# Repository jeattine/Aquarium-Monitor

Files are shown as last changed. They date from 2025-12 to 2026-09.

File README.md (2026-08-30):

# Aquarium monitor

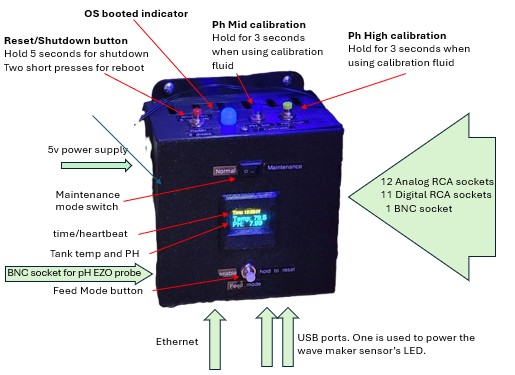
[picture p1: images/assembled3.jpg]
Assembled3


Python-based aquarium monitor program running under the Raspberry Pi OS Lite Linux operating system on a Raspberry Pi 4 board. A Adafruit Perma-Proto Hat is mounted on the board to house two MCP3008 10-bit ADC with SPI interface. An Atlas scientific PH EZO with isolated carrier board is attach to the I2C interface of the processor. The MCP3008's and the PH EZO provide the analog inputs to the monitor. The HAT also provides solder pads for each of the other GPIO pins used as digital inputs. The monitor has 23 RCA sockets and one BNC socket for input of the sensors. The BNC socket is used for the PH probe. One RCA socket is used for output for the alarm/maintenance_mode LED indicator. The monitor has a button to force a reset or a shutdown of the OS/monitor and a switch to enter a maintenance mode which disables alerts and enables pH calibration. There is also a Feed Mode button that allows pumps to be turned off during feeding without generating alerts. The monitor provides two buttons for the calibration of the PH probe, with a PH-Mid and a PH-High that can be set to the values of the calibration fluid in the configuration file or the override file. The calibration is saved internally and does not rely on providing external calibration data. When performing the calibration, the display will show *Maintenance* text along with the current pH value. The pH value display is helpful during pH calibration so that it can be seen that the PH values have stabilized with the probe in the calibration fluid. The condition of the pH probe in terms of a percentage from an ideal probe will be displayed in the OLED screen for 4 seconds after calibrating. A log file containing hourly snapshots of the PH value, Temperature, Calibration actions, Feed mode on/off, maintenance mode on/off, and Alerts can be observed in a cloud folder. A status file containing current information from all the sensors can be observed in the same cloud folder (dropbox and onedrive supported). I am using Dropbox as my cloud provider due to the simplicity of setting this up on Linux. The storing of the status and log file is accomplished using 'rclone copyto'. Monitor alerts are surfaced by emails sent to the recipients listed in the configuration file. The monitor will autostart after the Linux OS boots. It is started via a service and set to be restarted if it abnormally terminates or hangs using the WATCHDOG support in Linux. 

The program design has a 'Main' that constructs a Control object and loops calling methods on the Control object instantiation. 'Main' will stay in a continuous loop until an exception or a termination event causes it to exit. The input to the program is a config.txt file expected to be in the current directory. This file is composed of two sections. The first section assigns the port numbers of the hardware to various classes to read and process the sensor data connected to those port inputs. Some examples are classes to monitor temperature, Flow, water level, and light. These classes are derived from either a GPIO_Digital or a GPIO_Analog class, depending on the type of sensor. The GPIO_Digital class, GPIO_Analog class, and PH class are each derived from the Sensor base class. In addition to the port assignment to classes, this section of the config file also gives a descriptive name to each port input and defines the expected values/ranges/time-periods for operation. Another input to the program is the override.txt file. This file resides at a cloud location, either Dropbox or Onedrive depending on how the system is configured. This override file provides a convenient way to modify a subset of the settings in the config.txt file. For example when going on vacation I may want to modify the recipient list of the email alerts. I can do this by simply modifying the override file in the cloud folder from any device that has access to that folder. 

The utility Tailscale is installed on the monitor and on personal devices. This provides direct ssh access to the monitor via a split VPN tunnel directly between the personal devices and the monitor, allowing safe client SSH access to the monitor from outside the local home network. SSH access is useful if I need to perform a more drastic administrative or service action when away from home. When away from my primary laptop, the need may arise to modify the config.txt or the aquamon.py file. My iPAD and phone both have a dropbox application and Tailscale. On the iPAD I am using the Terminal# app which will get me into an SSH session. On the phone I use Termux. On the monitor I have two aliases set up: update-aquamon and update_config. They will use 'rclone copyto' to copy files from my local GitHub repository located in dropbox to the monitor. From there a systemctl restart put the new files in play. For an editor on the iPAD I am using Runestone. It's simple, lightweight, and color-codes nicely editing python code.

Code structure:

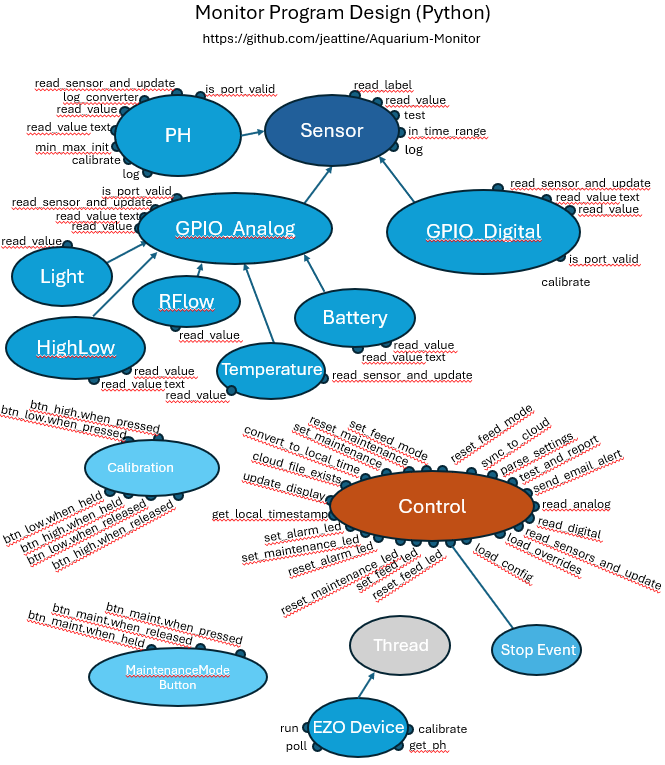
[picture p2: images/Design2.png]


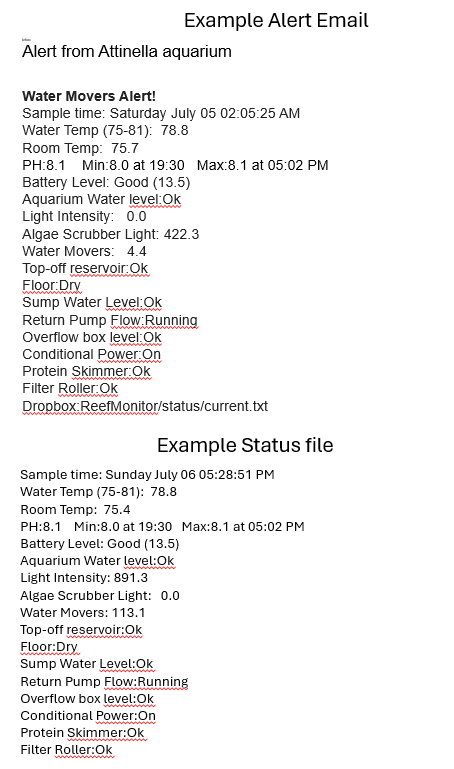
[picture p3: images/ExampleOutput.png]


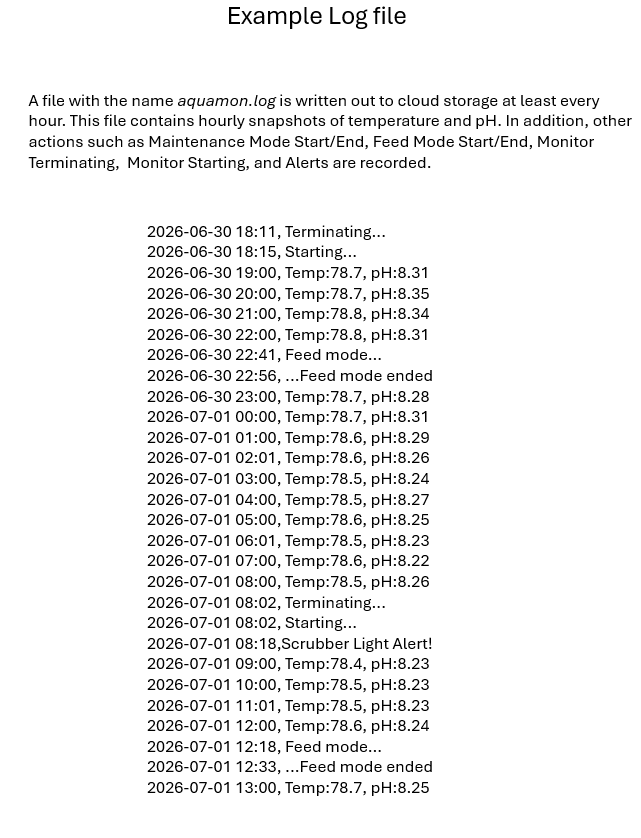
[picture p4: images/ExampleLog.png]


This is the bigger picture, showing the network interfaces and wiring to the various sensors:
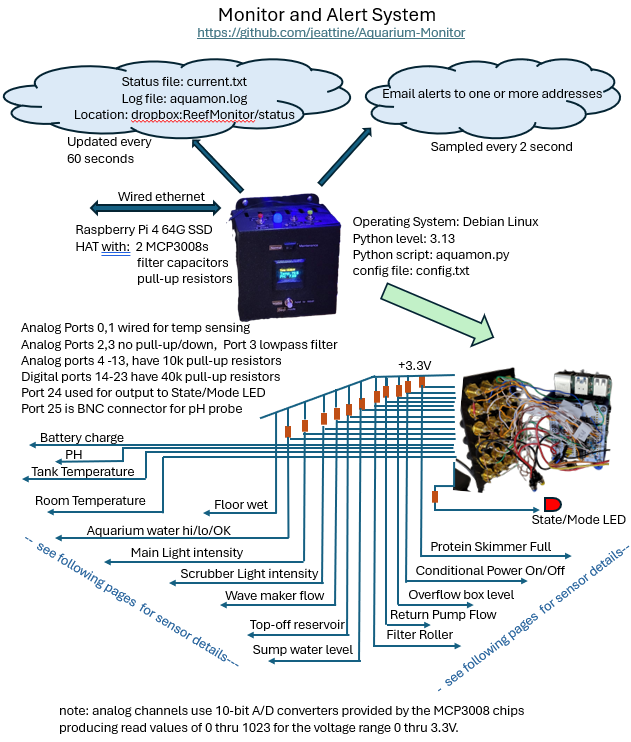
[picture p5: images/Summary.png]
Summary


The Raspberry Pi board, Perma-Proto Hat with the two MCP3008 ICs, and the wiring to the RCA inputs:

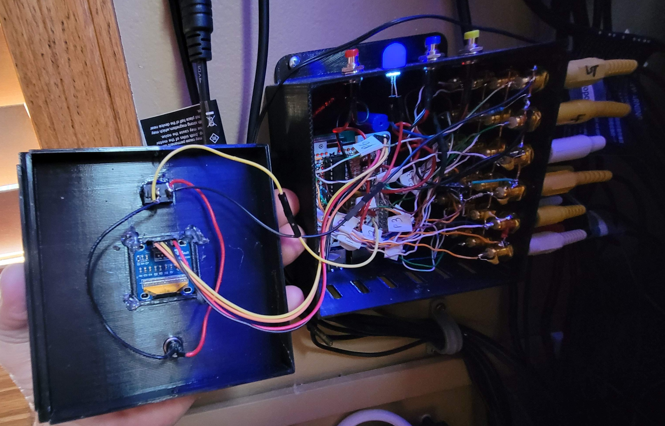
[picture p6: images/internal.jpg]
Internals


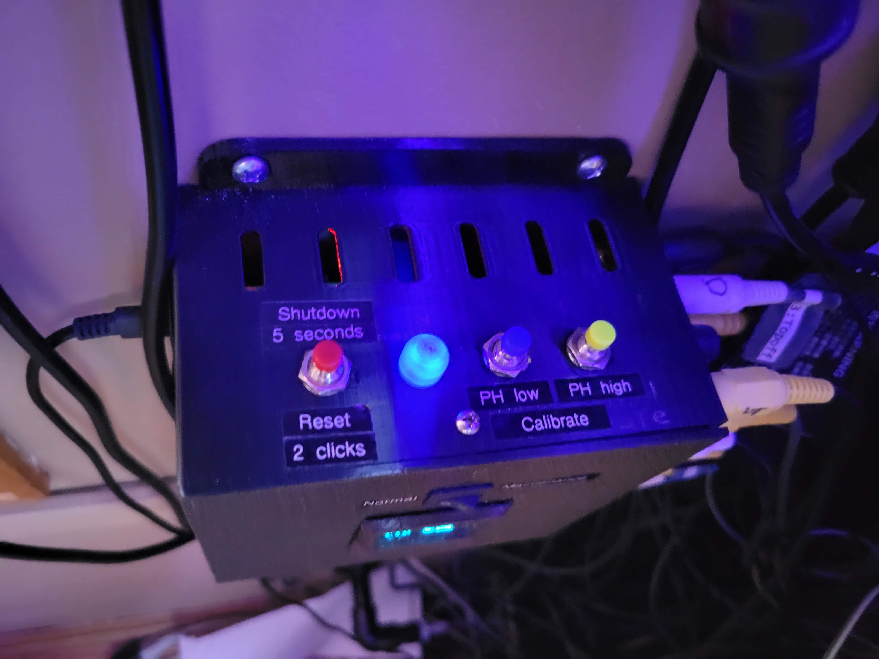
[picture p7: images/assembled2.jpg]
Assembled2


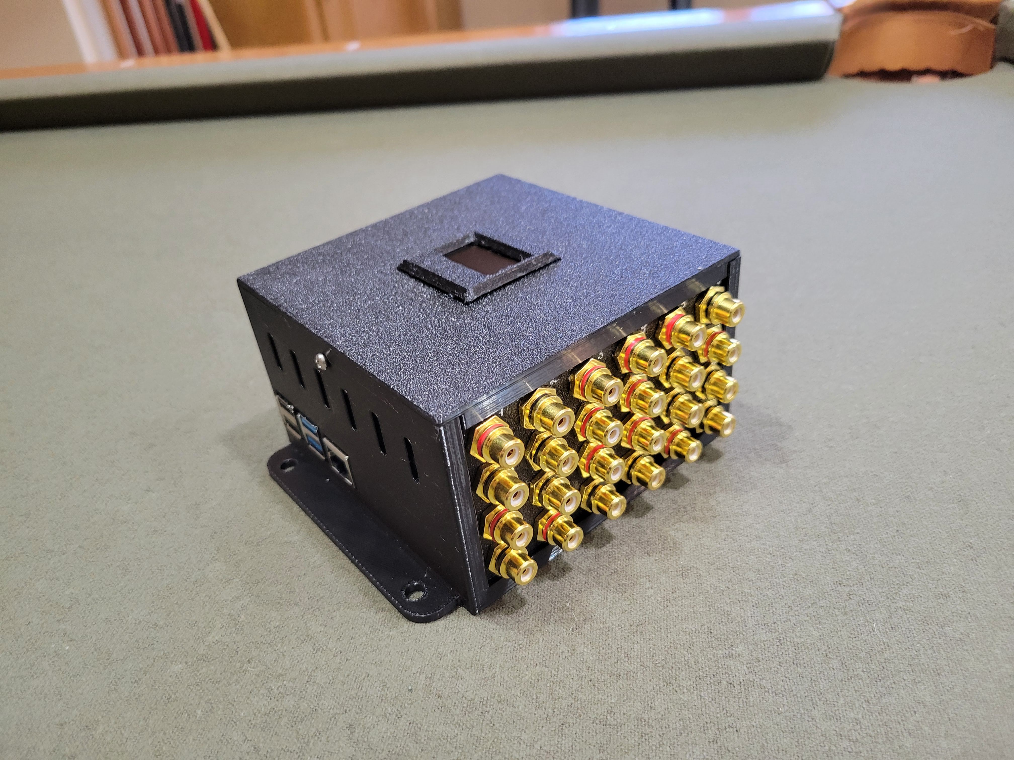
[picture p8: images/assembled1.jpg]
Assembled1


Internal wiring schematic:

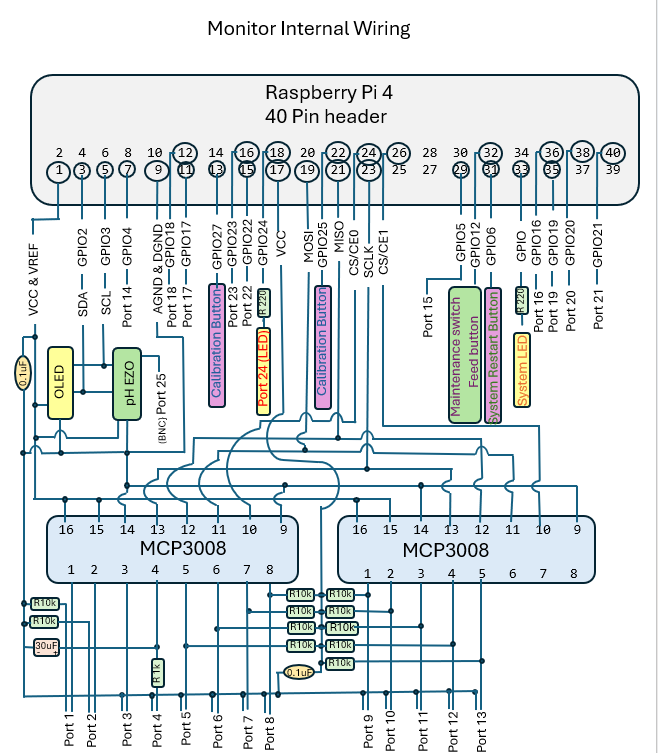
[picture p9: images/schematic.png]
Schematic


The following images show the various sensors that feed the monitor through the RCA ports:
  
***
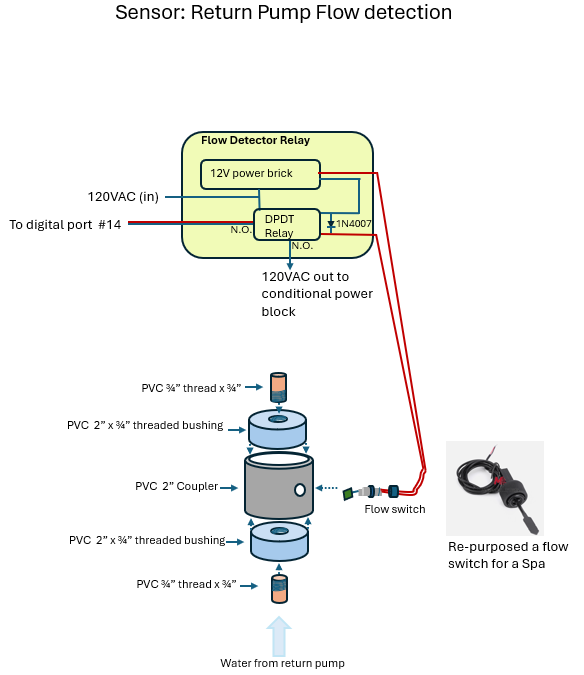
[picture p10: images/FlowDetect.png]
Flow Detection

  
***
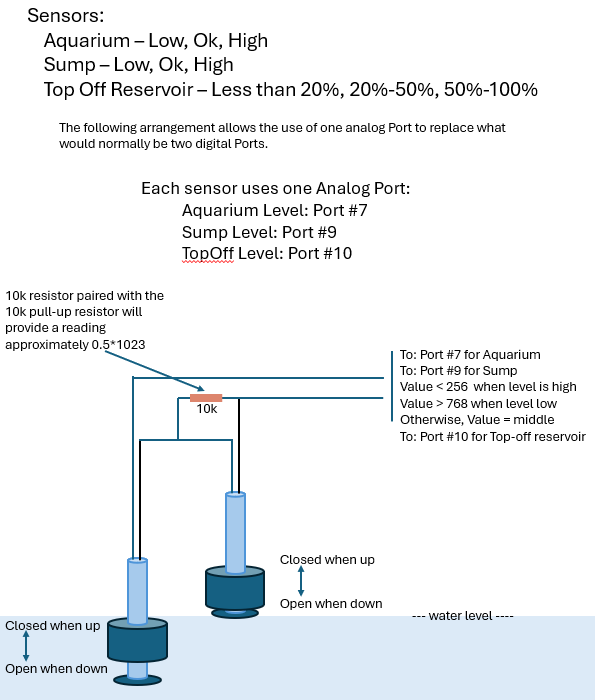
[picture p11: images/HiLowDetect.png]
Hi Low Level Detection

  
***
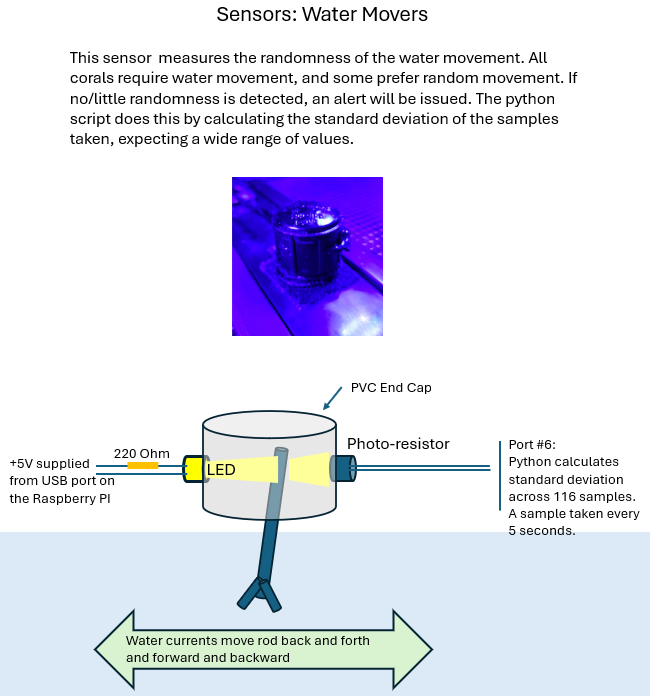
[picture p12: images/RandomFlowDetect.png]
Random Flow Detect

  
***
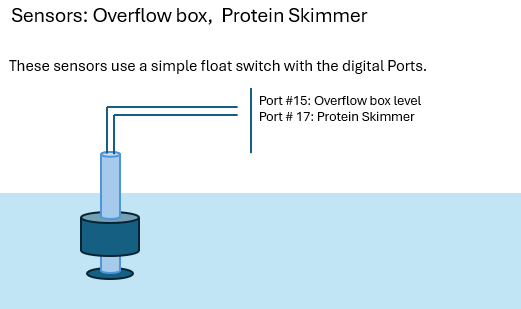
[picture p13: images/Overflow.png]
Overflow Detect

  
***
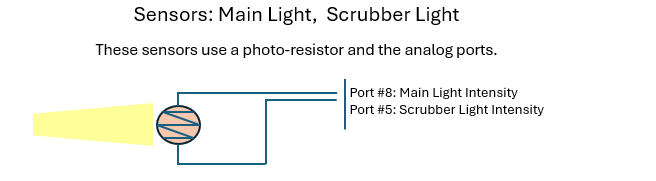
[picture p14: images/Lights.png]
Light Detect

  
***
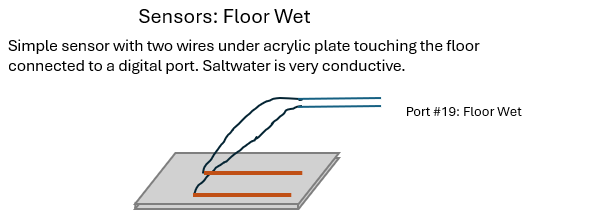
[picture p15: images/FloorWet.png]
Floor Wet Detect

  
***
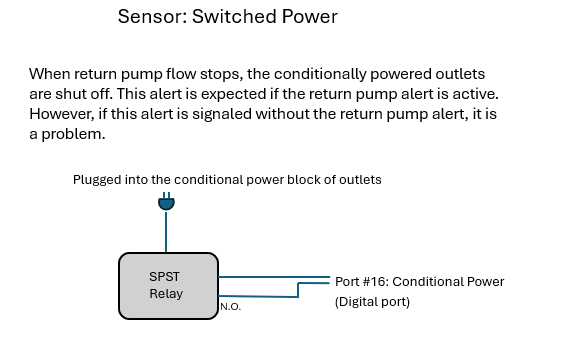
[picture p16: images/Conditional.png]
Conditional Detect

  
***
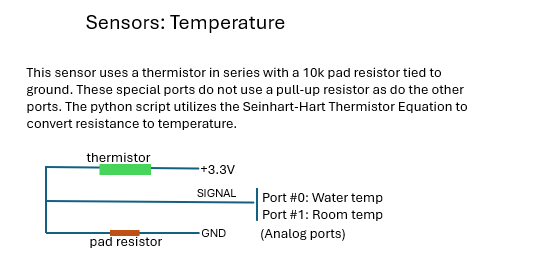
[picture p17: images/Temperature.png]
Temperature Detect

  
***
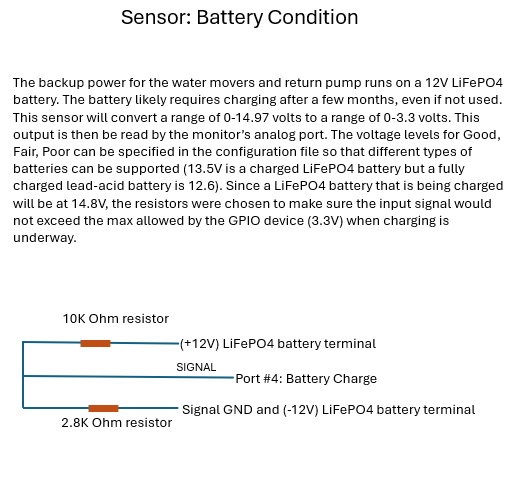
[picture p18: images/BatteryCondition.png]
Battery Condition

  
***
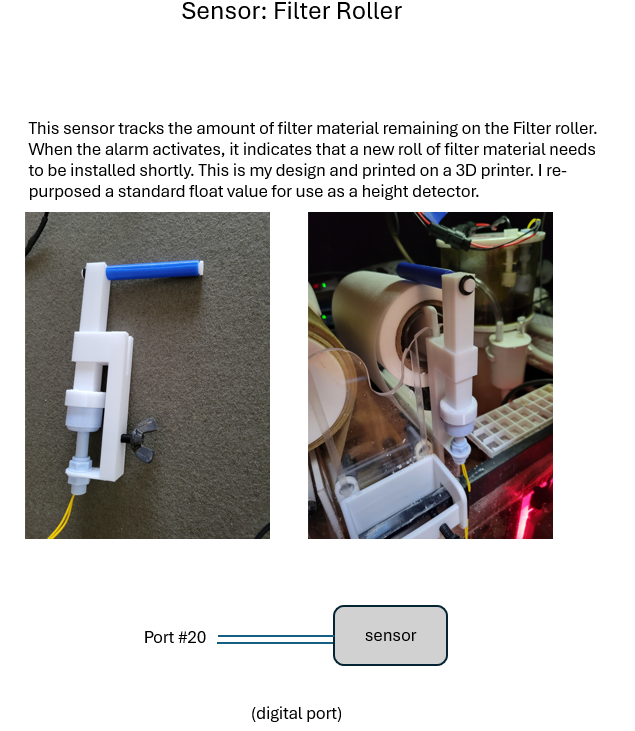
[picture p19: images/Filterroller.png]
Filter Roller

  
***
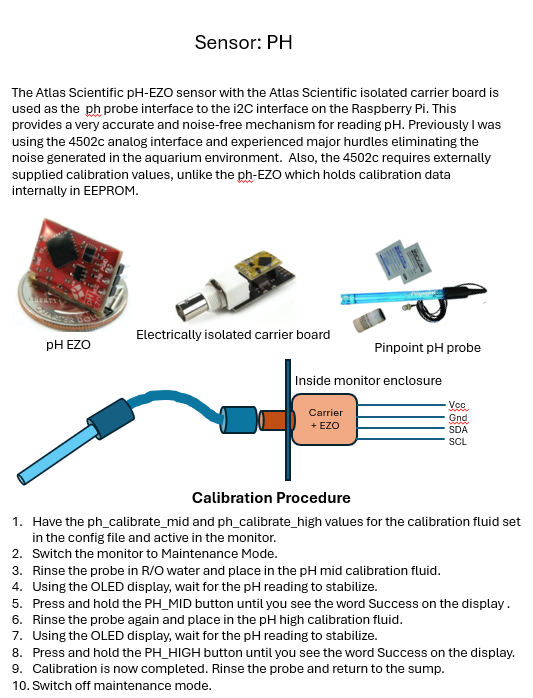
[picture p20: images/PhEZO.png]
PH

***

## Raspberry Pi Setup for the Aquarium Monitor

### Flash the OS

1.  Download the **Raspberry Pi Imager** on your Windows 11 machine.
2.  Select **OS**: _Raspberry Pi OS (64-bit) Lite_ (You don't need a desktop GUI).
3.  Select **Storage**: Your microSD card.
4.  **Gear Icon (Edit Settings)**:
    *   **Set hostname:** e.g., aquamon-local
    *   **Set username/password:** (e.g., pi and your chosen password).
    *   **Configure Wireless LAN:** Enter your SSID and Password.
    *   **Services Tab:** Check **Enable SSH** and use password authentication.
5.  Click **Write**.

### Connect via SSH

Once the card is flashed, pop it into the Pi and power it up. Wait about 2 minutes for the first boot.

1.  Open **PowerShell** on Windows 11.
2.  Type:
    ```
	ssh pi@aquamon.local
	```
	(replace pi and aquamon with the credentials you set).
3.  If it asks about "authenticity of host," type:
    ```
	yes
	```
4.  Enter your password. You are now "inside" the Pi.
5.  Finish and Reboot:
    ```
	sudo reboot
    ```	
	(You'll be disconnected; wait a minute and SSH back in).

### Environment Setup and Libraries

Modern Raspberry Pi OS (Bookworm) requires a **Virtual Environment (venv)** to prevent breaking system-wide packages.

### Update the system

```
sudo apt update sudo apt upgrade -y  
sudo apt install i2c-tools rclone swig liblgpio-dev python3-dev build-essential -y  
sudo apt-get install fonts-freefont-ttf  
curl -fsSL https://tailscale.com/install.sh | sh  
sudo tailscale up  
```

### Create a project folder

```
mkdir reef_monitor && cd reef_monitor
```

### Create and activate a Virtual Environment

```shell
python -m venv env
source env/bin/activate
```

### Install the necessary python libraries

```shell
pip install gpiozero spidev luma.oled smbus2 rpi-lgpio sdnotify  
```

### Enable Hardware Interfaces

The design uses **SPI** for the MCP3008s and **I2C** for the OLED and pH EZO. These are disabled by default.  
1.  In the SSH terminal:
    ```shell
	sudo raspi-config
	```
1.  Navigate to **Interface Options**.
1.  Enable **I2C** and **SPI**.

### Transfer the code

Since we are on Windows, the easiest way to move the .py and config.txt files to the Pi is using **SCP** (Secure Copy). Open a _new_ PowerShell window on your Windows desktop (not the one logged into the Pi) and run:  

```shell
scp aquarium_script.py config.txt pi@aquamon.local:~/reef_monitor/
```

### Set the environment variables and activate environment

The code uses os.environ.get('AQUAMON\_EMAIL'), etc. We need to define these on the Pi so the script can see them.  
1.  In your SSH session, open the profile file:
    ````shell
    nano ~/.bashrc
	````
2.  Scroll to the bottom and add the following:
    ````text
    export AQUAMON_EMAIL=[your_email@gmail.com](mailto:your_email@gmail.com)  
    export AQUAMON_EMAIL_PW="your_app_password"
	````
3.  Source the script:
    ````text
    source ~/reef_monitor/env/bin/activate
	````
4.  Save (**Ctrl+O, Enter**) and Exit (**Ctrl+X**).
5.  Refresh the variables:
    ```shell 
    source ~/.bashrc
	```

### Run and Automate

To test it: 

```shell 
python reef_monitor/aquarium_script.py
```
### Setup a systemd service to have it start on boot

In the SSH session, run the following command to create a new service file:

```shell
sudo nano /etc/systemd/system/reef_monitor.service
```
Service file:  
```text
[Unit]  
Description=Reef Aquarium Monitor Script  
After=network-online.target  
Wants=network-online.target  

[Service]
Type=notify  
User=aquamon  
# Add Environment variable here  
Environment="AQUAMON_EMAIL=aquamonemail@gmail.com"  
Environment="AQUAMON_EMAIL_PW=abcdefghijklmnop"  
# Path to your python interpreter and your script  
ExecStart=/home/aquamon/reef_monitor/env/bin/python3 -u /home/aquamon/reef_monitor/aquamon.py  
# Working directory (helps if your script loads fonts or images from its own folder)  
WorkingDirectory=/home/aquamon/reef_monitor  
# Restart logic  
Restart=always  
# Wait 10 seconds before restarting to prevent rapid-fire loops  
RestartSec=10s
WatchdogSec=180  

[Install]  
WantedBy=multi-user.target  
```

During developement/debug I would typically stop the service and run the the monitor in an ssh'ed terminal session. 

You must then enable the service. This creates a symlink (a shortcut) that tells the system to run this script when it reaches multi-user.target (normal bootup).  
```shell
sudo systemctl enable reef_monitor.service  
```
I also have a reef shutdown service that runs separately to provide restart and shutdown via buttons. This would done as a separate service so that if the monitor ends or is hung, the restart and shutdown button actions would still be active.

```shell
sudo nano /etc/systemd/system/reef_shutdown.service  
```

```text
[Unit]  
Description=Reef Monitor Hardware Shutdown Button  
After=network.target

[Service]  
Type=simple  
ExecStart=/usr/bin/python3 /home/aquamon/reef_monitor/shutdown_button.py  
Restart=always  
RestartSec=5  
User=root

[Install]  
WantedBy=multi-user.target  
```

Also enable this service:
```shell
sudo systemctl enable shutdown.service  
```

### Install Rclone

The command rclone copy is **one-way only**. It behaves like an "upload" or a "download". It will **not** try to synchronize with all files in the cloud folder.

*   Run rclone config on Raspberry Pi.
*   Name it dropbox, pick the dropbox number.
*   When it asks **"Use auto config?"**, type **n** (No).
*   Copy the command given (e.g., rclone authorize "dropbox") and run it on your Windows PC.
*   Log in to Dropbox in your browser, click **Allow**, and paste the resulting token back into the Pi.

### Setup aliases

```shell
nano ~/.bash_aliases  
```

```text
alias update-aquamon='rclone copyto dropbox:GitHub/Aquarium-Monitor/aquamon.py ~/reef_monitor/aquamon.py && echo "aquamon.py updated from local repo"'
alias update-config='rclone copyto dropbox:GitHub/Aquarium-Monitor/config.txt ~/reef_monitor/config.txt && echo "config.txt updated from local repo"'
alias monitor-logs='TZ="America/Chicago" journalctl -u reef_monitor.service --no-pager -n 40'
```

The update-\* aliases make code testing convenient. SSH to the system from your device, and assuming your device has dropbox access to the local repository directory, run the scripts to update the code and configuration files as needed.

## Managing the Monitor  

When the monitor is up and running via the reef_monitor service, use these commands to work with it:

| Task | Command |
| --- | --- |
| Check if it's running | sudo systemctl status reef\_monitor.service |
| Stop the monitor | sudo systemctl stop reef\_monitor.service |
| Restart monitor | sudo systemctl restart reef\_monitor.service |
| View past logs | monitor-logs |
| View live logs | sudo journalctl -u reef_monitor.service -f |
| Update monitor code | update-aquamon |
| Update config file | update-config |

## Tailscale periodic re-authentication

Tailscale requires periodic re-authentication (by default every 180 days) for security. Because Tailscale does not have its own separate username/password system, you authenticated using an existing Identity Provider (SSO) such as Google, Microsoft, GitHub, or Apple.  

**Step 1:** Identify Your Account.  Try these quick methods to figure out which email/account you used:Check your email inboxes: Search your personal email accounts (Google/Gmail, Microsoft, etc.) for Tailscale or "Welcome to Tailscale". Check browser history: Go to login.tailscale.com in your web browser. If you have active sessions or stored cookies, it may auto-redirect to your admin console or highlight the account provider you previously selected.

**Step 2:** Re-authenticate Your LaptopOpen the Tailscale desktop app or run tailscale up in your terminal.When prompted, log in using the identity provider (e.g., Google) linked to your primary account.  

**Step 3:** Re-authenticate Your Raspberry PiOnce you are logged into your primary account on your browser: Local Terminal Access: If your Pi is nearby, log in via a local terminal (or local network SSH) and run:

```shell 
sudo tailscale up --force-reauth
```

Follow the URL: Copy the URL output by the command and paste it into the browser where you are logged into Tailscale.

**(Optional) Disable Key Expiry:** To prevent the Pi from disconnecting again in 180 days: Go to the Tailscale Admin Console.Find your Raspberry Pi in the Machines list.Click the ... menu next to it and select Disable key expiry. You can do this for other mobile devices such as ipads and android phones.

## Monitor Enclosure

The enclosure and related parts were all printed on a 3D printer. I have included the FreeCad source files for these parts. They can be modified with FreeCad and/or exported to 3mf files for printing.  

***

# The Big Picture

The following diagrams depict my overall aquarium environment. The first diagram shows the interconnections of pumps, filters, lights, scrubber, monitor, etc.. The second diagram shows the management and plumbing of both saltwater and R/O water.  

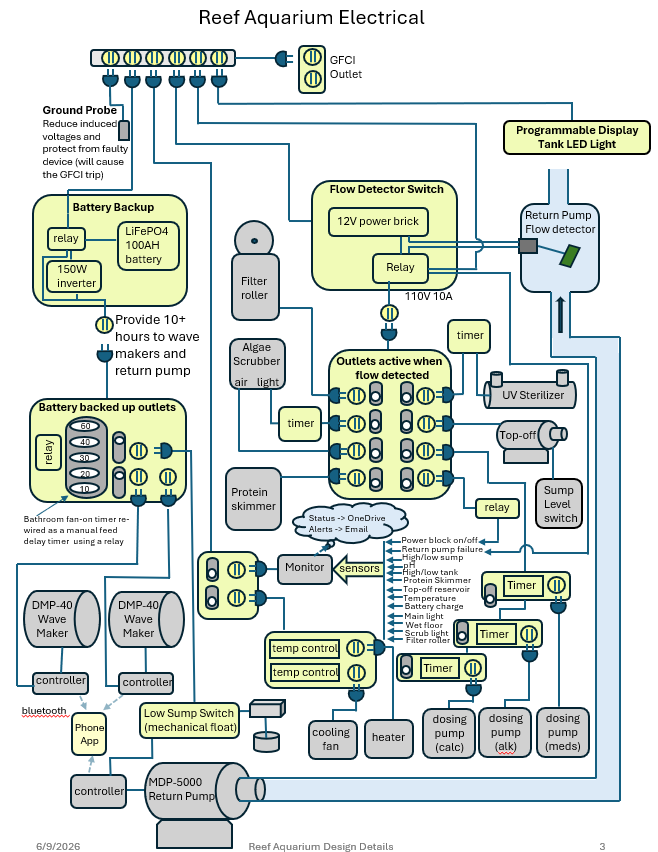
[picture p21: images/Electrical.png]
Electrical System
  

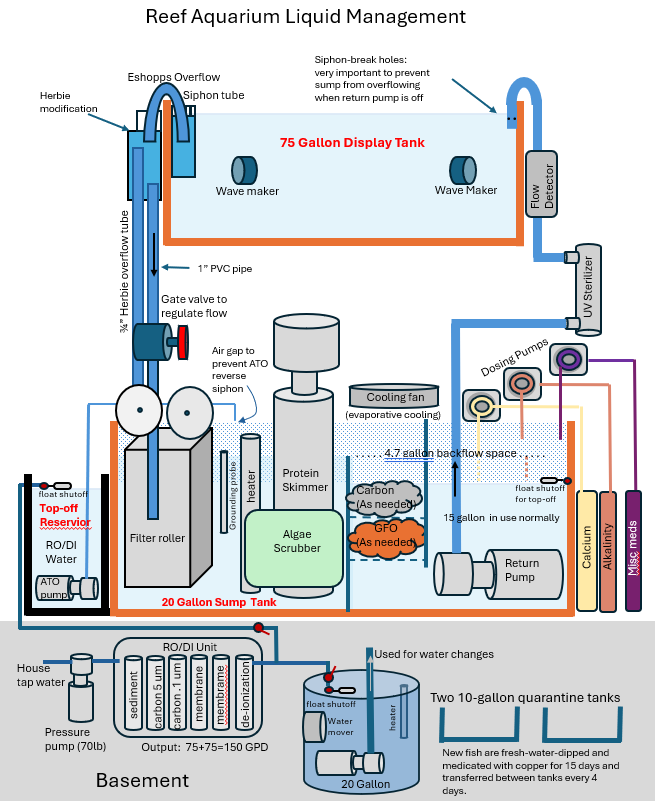
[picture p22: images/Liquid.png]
Liquid Management


# License Information

This project is licensed under the MIT License, except for the /Print3D folder, which is licensed under CC BY-NC 4.0.

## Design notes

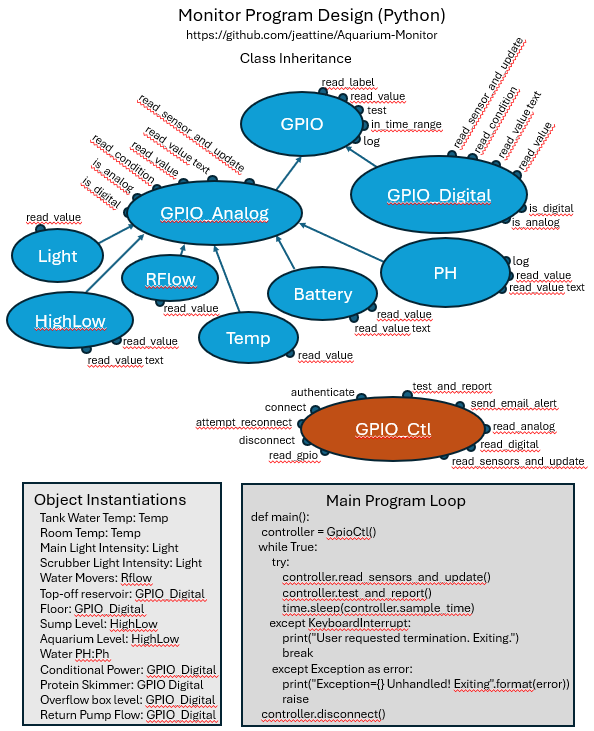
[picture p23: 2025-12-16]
images/Design.png

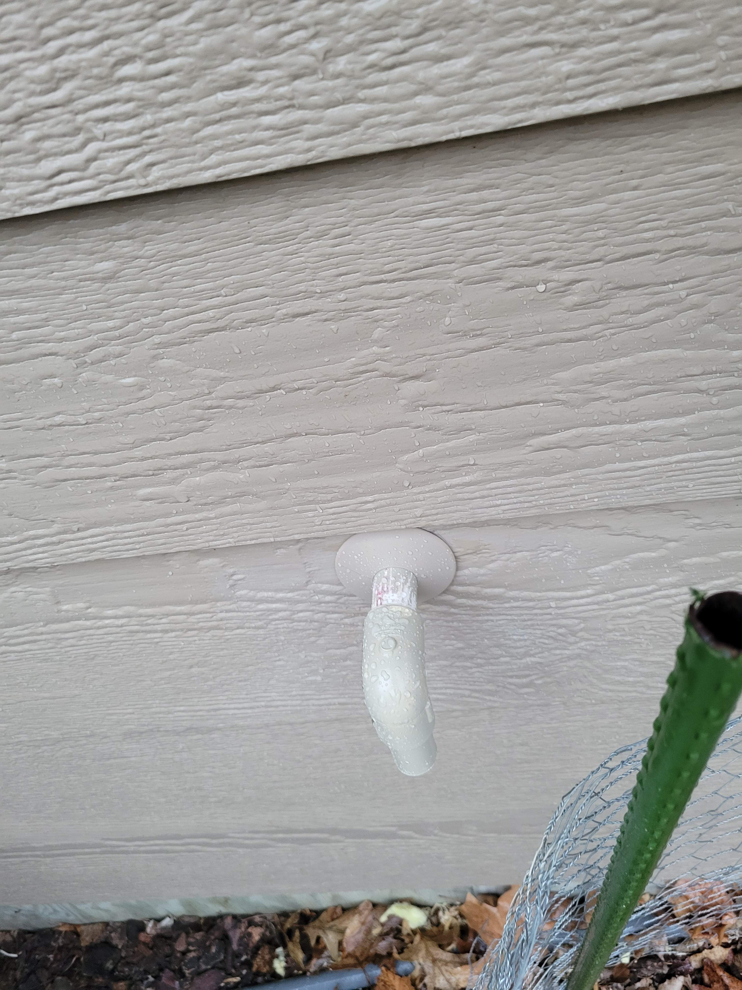
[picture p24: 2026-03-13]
images/OutsideAir3.jpg

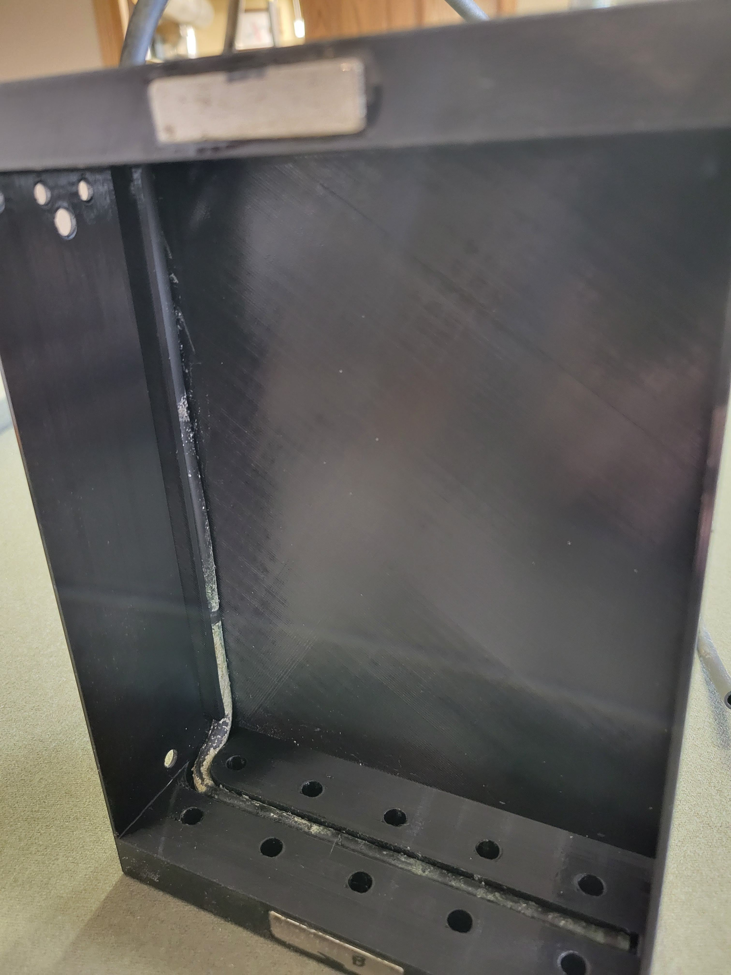
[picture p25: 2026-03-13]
images/scrubber2.jpg

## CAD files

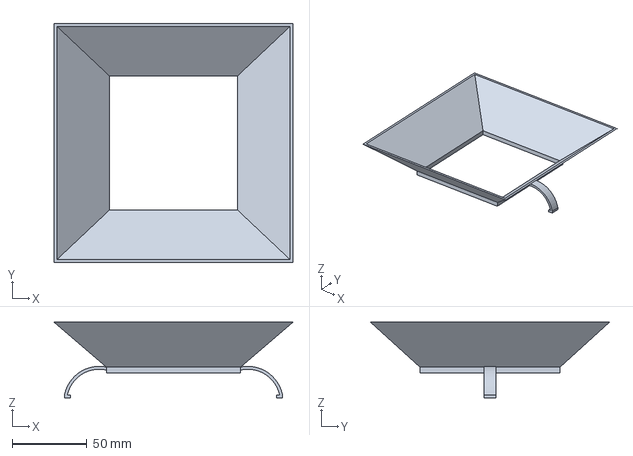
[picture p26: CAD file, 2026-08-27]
Print3D/AquariumStuff/LightShade.FCStd
160.0 x 160.0 x 50.6 mm

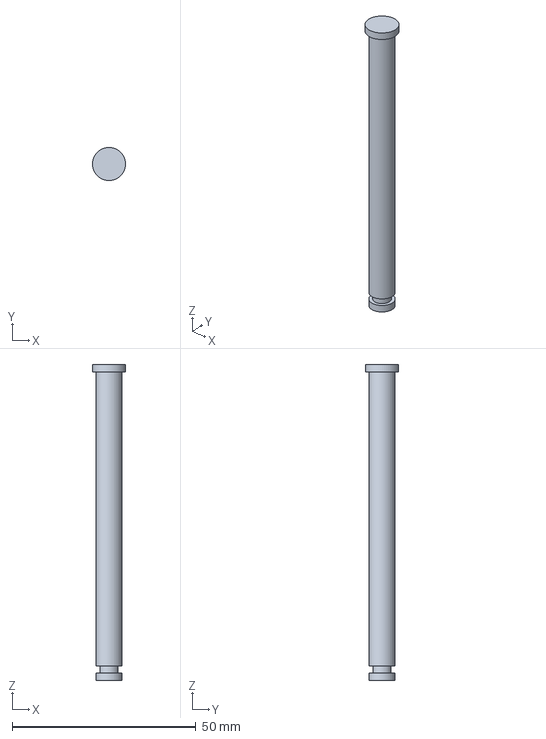
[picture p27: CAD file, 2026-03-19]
Print3D/FilterSensorP2.FCStd
8.99 x 9.00 x 86.0 mm

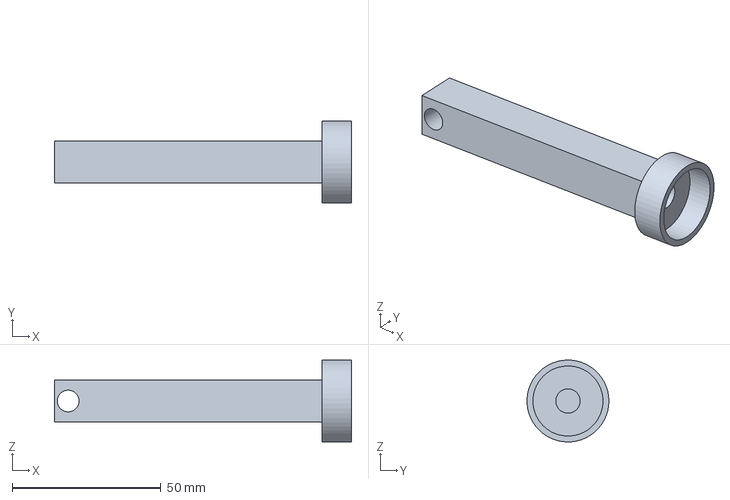
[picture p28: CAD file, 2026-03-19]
Print3D/FilterSensorP1.FCStd
100.0 x 27.6 x 27.6 mm

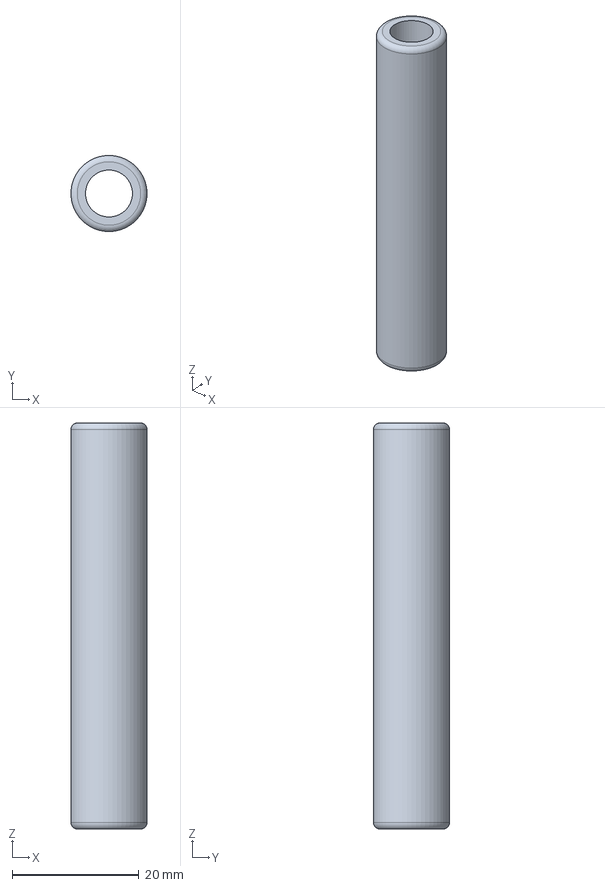
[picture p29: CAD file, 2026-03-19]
Print3D/FilterSensorP3.FCStd
12.0 x 12.0 x 64.0 mm

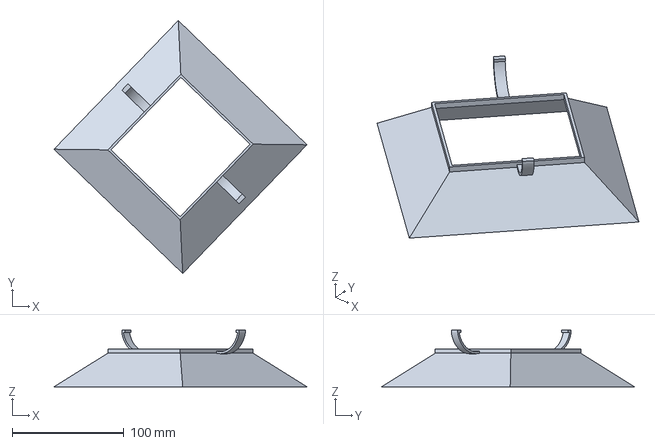
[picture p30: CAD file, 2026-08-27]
Print3D/AquariumStuff/LightShadeOffset-Body.3mf
226.2 x 226.2 x 50.6 mm

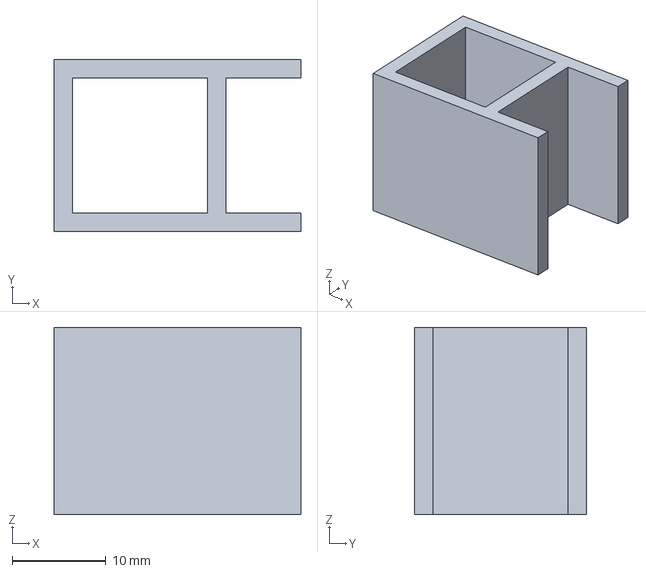
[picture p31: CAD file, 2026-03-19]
Print3D/FilterSensorP4.FCStd
26.4 x 18.4 x 20.0 mm

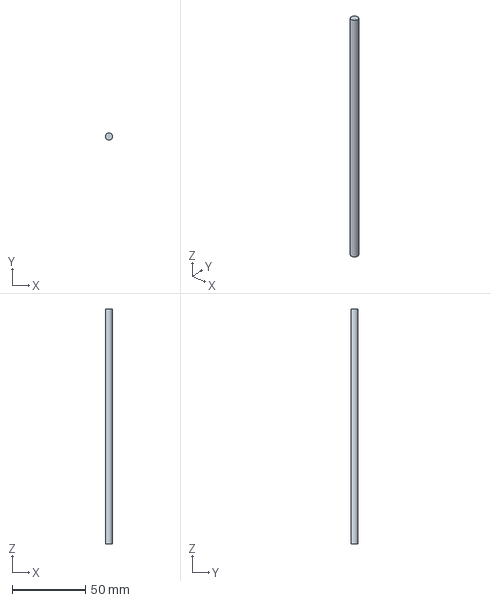
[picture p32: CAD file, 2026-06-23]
Print3D/AquariumStuff/AlgaeScrubberRod.FCStd
5.00 x 5.00 x 160.0 mm

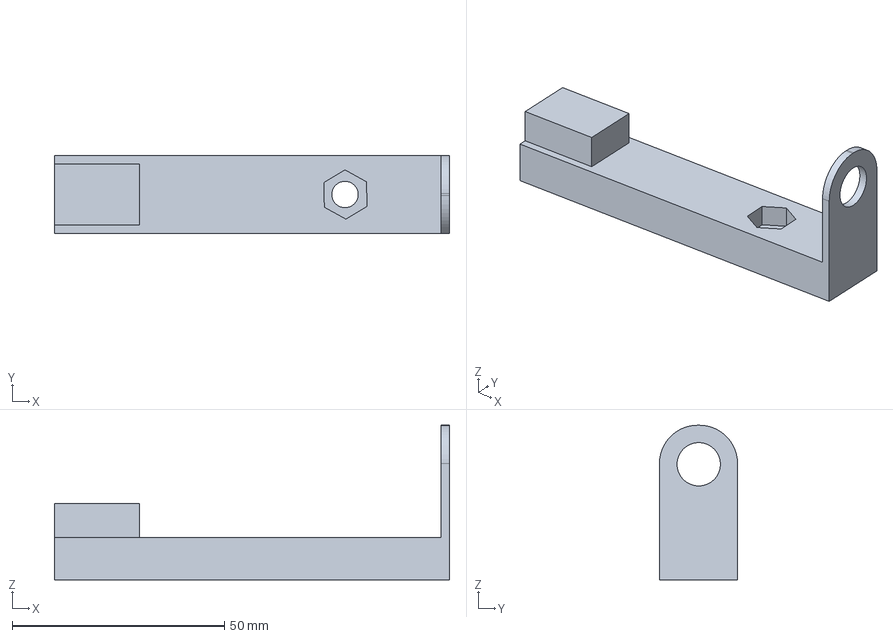
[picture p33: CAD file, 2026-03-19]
Print3D/FilterSensorP5.FCStd
93.0 x 18.4 x 36.4 mm

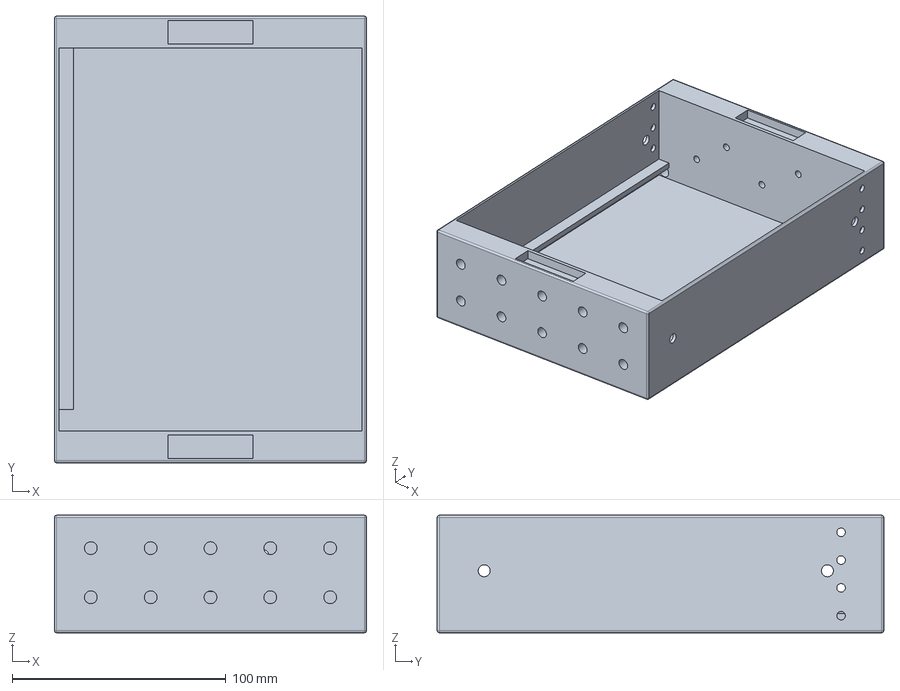
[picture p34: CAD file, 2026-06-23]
Print3D/AquariumStuff/AlgaeScrubber.FCStd
146.0 x 209.0 x 55.0 mm

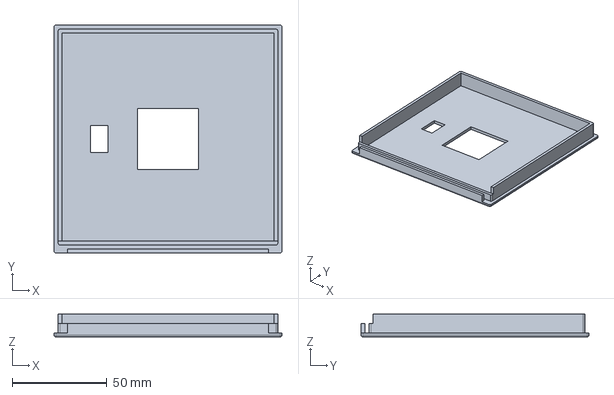
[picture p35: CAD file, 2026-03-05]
Print3D/MonitorTopPlate.FCStd
120.2 x 120.2 x 12.0 mm

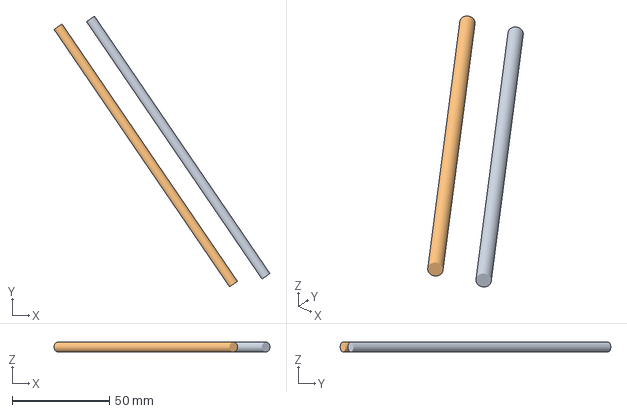
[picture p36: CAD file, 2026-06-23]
Print3D/AquariumStuff/AlgaeScrubberRod-Body.3mf
110.9 x 139.0 x 5.00 mm

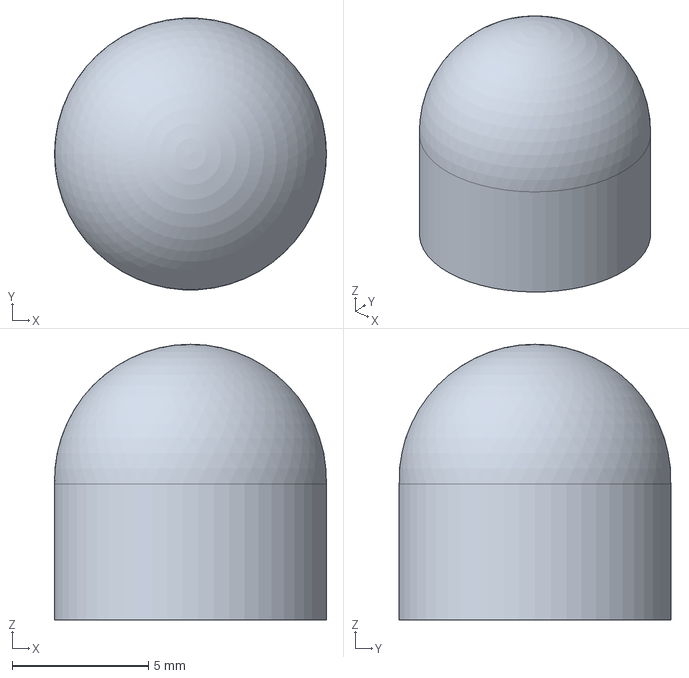
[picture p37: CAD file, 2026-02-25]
Print3D/LedCap.FCStd
10.0 x 9.98 x 10.1 mm

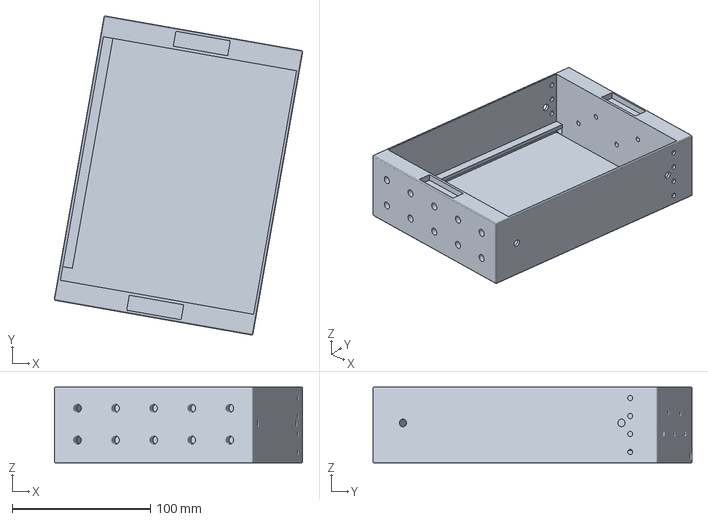
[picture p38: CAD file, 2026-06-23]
Print3D/AquariumStuff/AlgaeScrubber-Body.3mf
179.8 x 230.9 x 55.0 mm

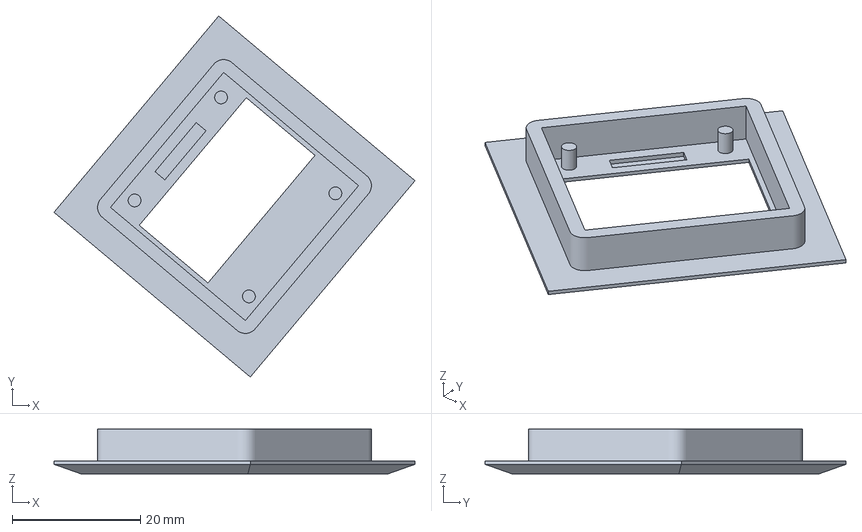
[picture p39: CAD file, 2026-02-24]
Print3D/OLED_bezel.3mf
56.4 x 56.4 x 7.00 mm

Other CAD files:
Print3D/AquariumStuff/LightShadeOffset.FCStd
Print3D/AquariumStuff/LightShade-Body.3mf
Print3D/Pin40Standoff.FCStd
Print3D/MonitorPlugPlate.FCStd
Print3D/MonitorEnclosure.FCStd

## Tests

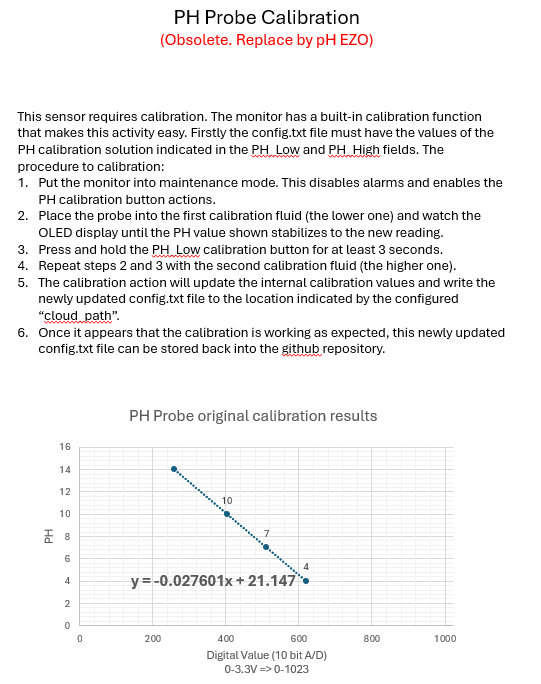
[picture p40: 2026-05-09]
images/Ph_calibrate.png

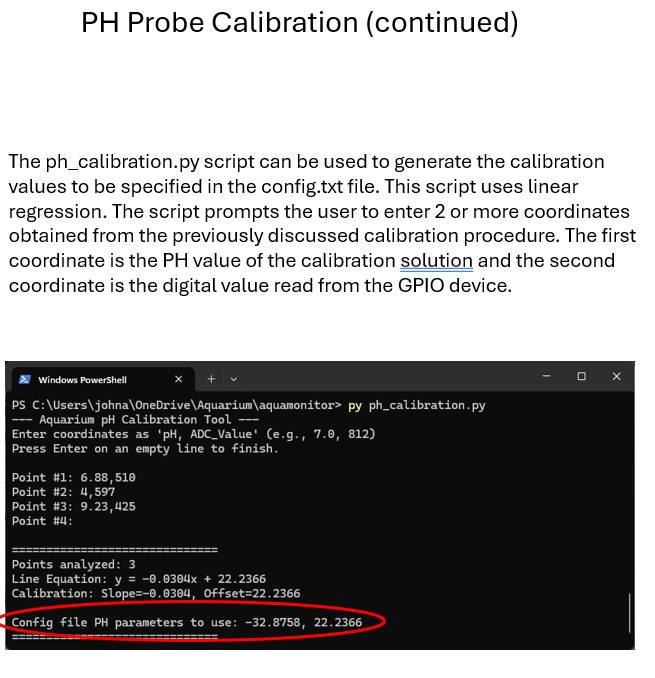
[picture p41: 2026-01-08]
images/Ph_calibrate2.png

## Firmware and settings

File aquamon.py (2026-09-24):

#!/usr/bin/env python3

# Script to monitor reef aquarium

import sys
import os
import shutil
import time
import math
import smtplib
import statistics
import logging
import socket
import subprocess
import spidev
import signal
import threading
import traceback
import sdnotify
from logging.handlers import RotatingFileHandler
from pathlib import Path
from datetime import timedelta, datetime
from zoneinfo import ZoneInfo, available_timezones
from email.mime.multipart import MIMEMultipart
from email.mime.text import MIMEText
from collections import deque
from gpiozero import DigitalInputDevice, Button, LED
from luma.core.interface.serial import i2c
from PIL import ImageFont
from luma.oled.device import ssd1306
from luma.core.render import canvas
from smbus2 import SMBus, i2c_msg

# --- HARDWARE I/O MAPPING ---
# MCP3008 Chip 0: Channels 0-7 -> Ports 1-8
# MCP3008 Chip 1: Channels 0-4 -> Ports 9-13 (unused channels 5,6,7)
# OLED: I2C Address 0x3C
# PH-EZO: I2C Address 0x63 (Port 25  BNC connector)
# GPIO 6  (pin 31) used for the system restart/shutdown button
# GPIO 12 (pin 32) is used for maintenance mode switch and feed mode button
# GPIO 13 (pin 33) is used for the system booted LED indicator
# GPIO 24 (pin 18) is used for the remote alarm/mode LED indicator
# GPIO 25 (pin 22) used for pH mid Calibrate button
# GPIO 27 (pin 13) used for pH High Calibrate button
# See Control:digital_map for the digital input GPIO and pin assignments

class Sensor:
    def __init__(self, controller, config_file_data):
        self.controller = controller
        self.config_info = config_file_data
        # Initialize very old time
        self.last_sent_alert = datetime.now(ZoneInfo("UTC")) - timedelta(days=365)
        self.test_active = False
        self.alarm_count = 0
        self.port = self.config_info[1].strip()
        self.nag_level = float(self.config_info[2].strip())
        self.label = self.config_info[3].strip()
        self.conditions = self.config_info[4].strip().split('+')

    def read_value(self):
        # Needs to be implemented in the derived classes
        raise NotImplementedError

    def read_value_text(self, value):
        # Needs to be implemented in the derived classes
        raise NotImplementedError

    def read_sensor_and_update(self):
        # Needs to be implemented in the derived classes
        raise NotImplementedError

    def is_port_valid(self):
        # Needs to be implemented in the derived classes
        raise NotImplementedError

    def test(self):
        c = self.controller
        current_value = self.read_value()
        utc_time = datetime.now(ZoneInfo("UTC"))
        if not self.test_active:
            start_delay_window = c.start_time + timedelta(seconds=120)
            if current_value < 0 or start_delay_window > utc_time:
                return current_value
            self.test_active = True
        if c.maintenance_mode or c.feed_mode:
            return current_value
        for condition in self.conditions:
            if ':' in condition:
                time_value = condition.split('?')
                timespan = time_value[0].split('-')
                time_start = timespan[0]
                time_end = timespan[1]
                value = time_value[1].split('-')
            else:
                time_start = ''
                time_end = ''
                value = condition.split('-')
            value_low = float(value[0])
            value_high = float(value[1 if len(value) == 2 else 0])

            # Are we in the indicated time range?
            if not time_start or self.in_time_range(time_start, time_end):
                if current_value < value_low or current_value > value_high:
                    # Set flag that an alarm is active during this round of sampling
                    c.alarm_active = True
                    c.alarm_text = self.label
                    # Read the nag level and timestamp of last email,
                    # If beyond the no-nag window, send the alert email.
                    nag_window = timedelta(hours=self.nag_level)
                    if (self.last_sent_alert + nag_window) < utc_time:
                        c.email_text.append(f'{self.read_label()} Alert!\n')
                        self.last_sent_alert = utc_time
                        # force a server update prior to sending the alarm
                        c.report_calls = c.server_update_freq / c.sample_time
                        self.alarm_count = self.alarm_count + 1
                        if self.alarm_count == 2:
                            # Reduce the interval
                            self.nag_level = self.nag_level/2
                        c.logger.info(f"{self.read_label()} Alert!")
                elif self.alarm_count:
                    self.alarm_count = 0

        return current_value

    def in_time_range(self, time_start, time_end):
        c = self.controller
        utc_time = datetime.now(ZoneInfo("UTC"))
        now = c.convert_to_local_time(utc_time).time()
        start = datetime.strptime(time_start, "%H:%M").time()
        end = datetime.strptime(time_end, "%H:%M").time()

        if start <= end:
            return start <= now <= end
        else: # Overnights (e.g., 22:00 to 02:00)
            return now >= start or now <= end

    def read_label(self):
        return self.label

    def log(self, value):
        # Let the derived classes optionally maintain a log.
        return ""

class GpioAnalog(Sensor):
    def __init__(self, controller, config_file_data, enable_averaging = True):
        super(GpioAnalog, self).__init__(controller, config_file_data)
        self.averaged_sample = -1.0
        self.enable_averaging = enable_averaging
        self.trim_amount = 8 # Trim 12.5% from top and bottom of sample buffer
        # create a 16 entry buffer with values spanning the 10 bit A/D converter range
        # Initialize a deque with a fixed maximum length.
        # This replaces manual slicing [1:]
        self.samples = deque(range(0, 1024, 64), maxlen=16)

    def read_value(self):
        return self.averaged_sample

    def read_value_text(self, value):
        return f'{value:5.1f}'

    def read_sensor_and_update(self):
         # Simply append; the oldest value is dropped automatically
        new_val = self.controller.read_analog(int(self.port))
        self.samples.append(new_val)
        # Create a running average. Dump (1/trim_amount) from highest/lowest samples
        if self.enable_averaging:
            temp_samples = sorted(list(self.samples))
            trim_low = int(len(temp_samples)/self.trim_amount)
            trim_high = int(len(temp_samples)) - trim_low
            temp_samples = temp_samples[trim_low:trim_high]

            self.averaged_sample = sum(temp_samples) / len(temp_samples)

    def is_port_valid(self):
        return int(self.port) in self.controller.analog_ports

class GpioDigital(Sensor):
    def __init__(self, controller, config_file_data):
        super(GpioDigital, self).__init__(controller, config_file_data)
        self.snapshot = -1
        self.previous_state = 0
        self.ones_count = self.zeros_count = 0
        self.ones_total = self.zeros_total = 0
        self.count_threshold = 3
        self.value_zero_text = self.config_info[5].strip()
        self.value_one_text = self.config_info[6].strip()

    def read_value(self):
        return self.snapshot

    def read_value_text(self, value):
        if value == 0:
            return self.value_zero_text
        elif value == 1:
            return self.value_one_text
        return 'Not Avail'

    def read_sensor_and_update(self):
        count = self.controller.read_digital(self.port)
        if count == 1:
            if self.previous_state == 0:
                self.previous_state = 1
                self.zeros_count = 0
            self.ones_count += 1
            self.ones_total += 1
        else:
            if self.previous_state == 1:
                self.previous_state = 0
                self.ones_count = 0
            self.zeros_count += 1
            self.zeros_total += 1
        if self.ones_count > self.count_threshold:
            self.snapshot = 1
        elif self.zeros_count > self.count_threshold:
            self.snapshot = 0

    def is_port_valid(self):
        return int(self.port) in self.controller.digital_ports

class FloorWetSensor(GpioDigital):
    def __init__(self, controller, config_file_data):
        super(FloorWetSensor, self).__init__(controller, config_file_data)

class TempSensor(GpioAnalog):
    def __init__(self, controller, config_file_data):
        super(TempSensor, self).__init__(controller, config_file_data)
        self.current_temp = 0
        self.ema_value = None
        self.alpha = 0.2  # Smoothing factor
        self.samples = deque([500] * 16, maxlen=16)
        self.pad_resistor = float(self.config_info[5].strip())
        self.calibration = float(self.config_info[6].lstrip())

        # Check if this instance is the primary water sensor
        self.is_water_sensor = "Water" in self.label

    def log(self, value):
            if self.is_water_sensor:
                # Logging library handles the timestamp and file writing
                return f"Temp:{value:2.1f}"

    def read_sensor_and_update(self):
        # Get trimmed mean from parent (GpioAnalog)
        super().read_sensor_and_update()
        current_trimmed_mean = self.averaged_sample

        # debugging
        #print(f"{self.samples}\n")

        # Apply Exponential Moving Average (EMA) to smooth jitter
        if self.ema_value is None:
            self.ema_value = current_trimmed_mean
        else:
            self.ema_value = (self.alpha * current_trimmed_mean) + (
                (1 - self.alpha) * self.ema_value
            )

        # Calculate Resistance
        if self.ema_value <= 0:
            self.current_temp = 0
            return

        # Vout = Vin * (R_pad / (R_therm + R_pad)) -> Solving for R_therm:
        resistance = ((1024 * self.pad_resistor / self.ema_value) - self.pad_resistor)

        # Steinhart-Hart Equation
        try:
            ln_r = math.log(resistance)
            A, B, C = 1.129148e-3, 2.34125e-4, 8.76741e-8
            temp_k = 1 / (A + B * ln_r + C * math.pow(ln_r, 3))

            # Convert Kelvin to Celsius
            temp_c = temp_k - 273.15
            # Convert to Fahrenheit
            temp_f = (temp_c * 9.0) / 5.0 + 32.0

            # Adjust with calibration offset from config
            self.current_temp = temp_f + self.calibration

            # Update Controller's display variable
            if self.is_water_sensor:
                self.controller.display_temp = self.current_temp

        except (ValueError, ZeroDivisionError):
            self.current_temp = 0

    def read_value(self):
        return self.current_temp

class RandomFlowSensor(GpioAnalog):
    def __init__(self, controller, config_file_data):
        super(RandomFlowSensor, self).__init__(controller, config_file_data, False)
        # set the sample buffer to 128 entries
        self.samples = deque(range(0,1024,8), maxlen=128)

    def read_value(self):
        # Convert the sample data into a standard deviation
        return statistics.stdev(self.samples)

class LightSensor(GpioAnalog):
    def __init__(self, controller, config_file_data):
        super(LightSensor, self).__init__(controller, config_file_data)

    def read_value(self):
        light_level = 1023 - self.averaged_sample
        return light_level

class ThreeState(GpioAnalog):
    def __init__(self, controller, config_file_data):
        super(ThreeState, self).__init__(controller, config_file_data)
        self.low_level_text = self.config_info[5].strip()
        self.mid_level_text = self.config_info[6].strip()
        self.high_level_text = self.config_info[7].strip()
        # Assumes 10K resistor across upper sensor
        self.boundary_high = 768.0
        self.boundary_low = 256.0

    def read_value(self):
        level = self.averaged_sample
        return level
    def read_value_text(self, value):
        if value > self.boundary_high:
            return self.low_level_text
        elif value < self.boundary_low:
            return self.high_level_text
        return self.mid_level_text

class FourState(GpioAnalog):
    def __init__(self, controller, config_file_data):
        super(FourState, self).__init__(controller, config_file_data)
        self.level1_text = self.config_info[5].strip()
        self.level2_text = self.config_info[6].strip()
        self.level3_text = self.config_info[7].strip()
        self.level4_text = self.config_info[8].strip()
        #   Assumes:
        #   5K across upper sensor
        #   15K across middle sensor
        #   none across lower sensor
        self.boundary1_2 = 172.0
        self.boundary2_3 = 512.0
        self.boundary3_4 = 854.0

    def read_value(self):
        level = self.averaged_sample
        return level
    def read_value_text(self, value):
        if value > self.boundary3_4:
            return self.level4_text
        elif value > self.boundary2_3:
            return self.level3_text
        elif value > self.boundary1_2:
            return self.level2_text
        return self.level1_text

class Battery(GpioAnalog):
    def __init__(self, controller, config_file_data):
        super(Battery, self).__init__(controller, config_file_data)
        # initialize buffer with a value close to what is expected
        self.samples = deque([910] * 16, maxlen=16)
        self.good_fair_threshold = float(self.config_info[5].strip())
        self.fair_bad_threshold = float(self.config_info[7].strip())
        self.good_text = self.config_info[6].strip()
        self.fair_text = self.config_info[8].strip()
        self.bad_text = self.config_info[9].strip()
        # (+12V battery)--(10K ohm)--(+GPIO input)--(2.8K ohm)--(-battery)--(-GPIO)
        self.voltage_scaling = 68.2 # 0V-15V --> 0V-3.3V --> digital 0-1023

    def read_value(self):
        voltage = self.averaged_sample/self.voltage_scaling
        return voltage

    def read_value_text(self, value):
        if value > self.good_fair_threshold:
            return f"{self.good_text} ({value:2.1f})"
        elif value > self.fair_bad_threshold:
            return f"{self.fair_text} ({value:2.1f})"
        return f"{self.bad_text} ({value:2.1f})"

class Ph(Sensor):
    def __init__(self, controller, config_file_data):
        super(Ph, self).__init__(controller, config_file_data)
        self.current_ph = 6.0
        self.raw_mid = None
        self.raw_high = None
        self.min_max_init(datetime.now(ZoneInfo("UTC")))
        self.day_stamp = 0  # Initialization on first sensor read after timezone is avail
        self.poll_frequency = int(self.config_info[5].strip())

        try:
            self.ph_ezo = EzoDevice(controller, self, address=0x63)
        except Exception as e:
            sys.exit(f"Could not create PH monitor thread object. {e}")

    def start_thread(self):
        self.ph_ezo.start()

    def terminate_thread(self):
        self.ph_ezo.running = False
        self.ph_ezo.join(timeout=1)
        if self.ph_ezo.is_alive():
            print("Warning: pH ezo thread did not exit gracefully.")
        else:
            print("pH_ezo thread ended gracefully.")

    def read_sensor_and_update(self):
        c = self.controller
        self.current_ph = self.ph_ezo.get_ph()
        # Do min/max reporting daily
        utc_time = datetime.now(ZoneInfo("UTC"))
        local_time = c.convert_to_local_time(utc_time)
        current_day = local_time.day
        if current_day != self.day_stamp:
            # Start a new max/min period of recording
            self.min_max_init(local_time)
            self.day_stamp = local_time.day

        # Record PH in controller for Display Panel
        c.display_ph = self.current_ph

        if self.test_active and not c.maintenance_mode:
            if self.current_ph > self.max_ph:
                self.max_ph = self.current_ph
                self.max_timestamp = local_time
            if self.current_ph < self.min_ph:
                self.min_ph = self.current_ph
                self.min_timestamp = local_time

    def read_value(self):
        return self.current_ph

    def min_max_init(self, local_time):
        self.max_ph = 4
        self.min_ph = 12
        self.max_timestamp = local_time
        self.min_timestamp = local_time

    def log(self, value):
            # Logging library handles the timestamp and file writing
            return f"pH:{value:2.2f}"

    def read_value_text(self, value):
        # need to include the mix/max values/timestamps
        min_ts = self.min_timestamp.strftime("%I:%M %p")
        max_ts = self.max_timestamp.strftime("%I:%M %p")
        return f"{value:2.2f}  max:{self.max_ph:3.2f} at {max_ts}  min:{self.min_ph:3.2f} at {min_ts}"

    def is_port_valid(self):
        return int(self.port) in self.controller.i2c_ports

class CalibrationButtons:
    def __init__(self, controller):
        self.ph_sensor = controller.ph_sensor
        self.controller = controller
        self.btn_mid = Button(25, bounce_time=0.1, hold_time=3)
        self.btn_high = Button(27, bounce_time=0.1, hold_time=3)

        self.btn_mid.when_pressed = self._handle_mid_pressed_button
        self.btn_high.when_pressed = self._handle_high_pressed_button
        self.btn_mid.when_held = self._handle_mid_held_button
        self.btn_high.when_held = self._handle_high_held_button
        self.btn_mid.when_released = self._handle_mid_released_button
        self.btn_high.when_released = self._handle_high_released_button

    def _handle_high_pressed_button(self):
        if self.controller.maintenance_mode:
            self.controller.calibrate_text = "Cal HIGH"
            self.controller.set_calibrate_mode()
            with self.controller.i2c_lock:
                self.controller.update_display()

    def _handle_mid_pressed_button(self):
        if self.controller.maintenance_mode:
            self.controller.calibrate_text = "Cal MID"
            self.controller.set_calibrate_mode()
            with self.controller.i2c_lock:
                self.controller.update_display()

    def _handle_high_held_button(self):
        if self.controller.maintenance_mode:
            if self.ph_sensor.ph_ezo.calibrate("high", self.controller.ph_calibrate_high):
                self.controller.calibrate_text = "Success"
            else:
                self.controller.calibrate_text = "Failed"
            with self.controller.i2c_lock:
                self.controller.update_display()
            self.controller.logger.info(f"High calibration {self.controller.calibrate_text}")

    def _handle_mid_held_button(self):
        if self.controller.maintenance_mode:
            if self.ph_sensor.ph_ezo.calibrate("mid", self.controller.ph_calibrate_mid):
                self.controller.calibrate_text = "Success"

            else:
                self.controller.calibrate_text = "Failed"
            with self.controller.i2c_lock:
                self.controller.update_display()
            self.controller.logger.info(f"Mid calibration {self.controller.calibrate_text}")


    def _handle_mid_released_button(self):
        if self.controller.maintenance_mode:
            self.controller.reset_calibrate_mode()

    def _handle_high_released_button(self):
        if self.controller.maintenance_mode:
            result_str = self.ph_sensor.ph_ezo.probe_health()
            if result_str is not None:
                result_list = result_str.split(",")
                self.controller.calibrate_text = f"{result_list[2]}%, {result_list[3]}"
                with self.controller.i2c_lock:
                    self.controller.update_display()
                time.sleep(4)
            self.controller.reset_calibrate_mode()
            self.controller.logger.info(f"Probe {self.controller.calibrate_text}")

class MaintenanceModeButton:
    def __init__(self, controller):
        self.controller = controller
        self.btn_maint = Button(12, pull_up=True, bounce_time=0.1, hold_time=3)
        self.btn_maint.when_held = self.controller.set_maintenance
        self.btn_maint.when_released = self.controller.reset_maintenance
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

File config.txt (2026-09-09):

#------------------------------------------------------------------------------------
#Class, Port, Nag, Label,             Condition,        Class specific parms
#------------------------------------------------------------------------------------
#####################  a n a l o g  s e n s o r  s e c t i o n  ######################
temp,    1, 8,  Room Temp,           60-82,           10020, 0.3
temp,    2, 2,  Water Temp,          75-82,           10020,  2.3
#gpioa,  3, 0,  (unused analog),     NA,              NA
battery, 4,24,  Battery,             13.2-15.0,       13.2, Good, 12.9, Fair, Poor
light,   5, 8,  Scrubber Light,      21:15-09:45?200-1023+10:15-20:45?0-300
rflow,   6, 1,  Wave Makers,         14:20-14:00?10-500, NA, NA
3state,  7, 1,  Water level,         14:20-14:00?256-768, Low, Ok, High
light,   8, 2,  Main Light,          11:50-18:40?900-1023+22:00-08:00?0-550
3state,  9, 1,  Sump Level,          14:20-14:00?256-768, Low, Ok, High
3state, 10, 8,  Top-off reservoir,   0-768,           Less than 20%, 20-50%, 50-100%
#gpioa, 11, 0,  (unused analog),     NA,              NA
#gpioa, 12, 0,  (unused analog),     NA,              NA
#gpioa, 13, 0,  (unused analog),     NA,              NA
#
###################  d  i g i t a l   s e n s o r   s e c t i o n  ##################
gpiod,  14,  1,  Return Pump,         14:20-14:00?0,   Running, Shutdown
gpiod,  15,  4,  Overflow box,        1,               High, Ok
gpiod,  16,  1,  Switched Power,      14:20-14:00?0,   On, Off
gpiod,  17,  4,  Protein Skimmer,     1,               Full, Ok
#gpiod, 18,  4,  (unused),            NA,              NA
floor,  19,  1,  Floor,               1,               Wet, Dry
gpiod,  20,  8,  Filter Roller,       1,               Low, Ok
#gpiod, 21,  0,  (unused digital),    NA,              NA
#gpiod, 22,  0,  (unused digital),    NA,              NA
#gpiod, 23,  0,  (unused digital),    NA,              NA
#gpiod, 24,  0,  (Output port for a status LED on cabinet)
#
####################  I 2 C   s e n s o r   s e c t i o n  ##########################
ph,     25,  2, PH,                  7.8-8.5,          30
#
#
# Notes: 1. Ports 1,2 are wired special for temperature sensing:
#           GND --'internal 10K pad resistor'--'EXTERNAL THERMISTOR'-- GPIO input
#        2. Ports 3,4 do not have pull-up resistors and can be used for voltage sensing
#        3. Port 3 has a low-pass filter for additional noise reduction
#        4. Ports 5-23 are wired with a 10K pull-up resistor
#        5. Ports 1-13 are analog interfaces and only support analog class objects
#        6. Ports 14-23 are digital input interfaces and support digital class objects
#        7. Port 24 has an internal 220 ohm resistor wired in series for LED attach
#        8. 'Nag' is the number of hours before sending another alert for
#           a specific condition violation that has not cleared.
#        9. Port 25 is BNC to a PH EZO on AS isolated carrier board using i2c interface
#
#------------------------------------------------------------------------------------
# Network and Sampling Configuration
#------------------------------------------------------------------------------------
# Seconds between updates of the cloud-based status file
server_update_freq=60
# Seconds between sampling the input ports
sample_time=2
# PH high calibration solution at 25 C
ph_calibrate_high=10.01
# PH mid calibration solution at 25 C
ph_calibrate_mid=7.01
# Active maintenance mode warning timeout in minutes
maintenance_timeout=30
# Feed mode timeout in minutes
feed_timeout=15
# smtp server to use for sending alerts
smtp=smtp.gmail.com
# Subject line in the alert email
email_subject=Alert from Attinella aquarium
# Cloud provider
cloud_provider=dropbox
# Cloud path
cloud_path=ReefMonitor
# Time zone for status and reports (standard IANA Time Zone name)
timezone=America/Chicago
# Comma separated list of email recipients
email_recipients=

#--------------------------------------------------------------------------------
#  Required Environment Variables
#--------------------------------------------------------------------------------
#  AQUAMON_EMAIL: The 'from' address of the alert email sent by the monitor
#  AQUAMON_EMAIL_PW: The SMTP password for sending the alert email
#

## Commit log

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2025-11-22 Add Battery Monitor Class
    Add a class to monitor the battery used for backup power.
    [config.txt]
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2025-12-16 Update file specification format
    Pull the local path information out of the file specifications in the config.txt file. Have the local path information given in a separate config setting. Also do not hard-code the digital value when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
    [config.txt]
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2026-01-02 fix naming capitalization probem
2026-01-04 Lots of cleanup
    1. Improved algorithm to read in configuration info
    2. Moved sensitive info out of program and config file an into environment variables.
    3. Simplified the time range checks
    4. Removed the writing of the local status file every time the GPIOs were read.
    5. Improved the processing of the sample buffers using a deque object instead of list slicing.
    [config.txt]
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2026-01-09 Resolve parsing conflict with equal sign
    The new parsing logic was failing because the equal character was used in both the sensor section and the global settings section within the config.txt file. Replaced the use of the equal charrater with a question mark character in the sensor condition syntax. This was thought to be a better solution over adding additional code to the parsing logic.
    [config.txt]
2026-01-09 Update aquamon.py
    No longer need to test for an equal sign in the sensor section when processing the global settings since the syntax was change in the previous commit to eliminate this using the same special characters across these two sections of the config.txt file.
    [aquamon.py]
2026-01-09 Move GPIO password into an Env var
    Move the gpio password specification from the config file into an environment variable. Also add an explicit test to make sure all required env vars are present before starting the monitor.
    [config.txt]
2026-01-11 Update config.txt for auto feeding schedule
    Add time period from 2pm-2:20pm for automatic feeding. i.e. do not check for return pump, conditional power, aquarium level, sump level, and water movers during this period.
    [config.txt]
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2026-01-30 Documentation updates
    Documentation updates and back out the testing for SSID since it is not necessary and will not work if the system is attached via ethernet cable.
    [aquamon.py]
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2026-02-24 The new Raspberry Pi based monitor (#2)
    * Begin rewrite for Raspberry PI
    This is a big re-write for running the monitor standalone on a Raspberry Pi. This is the first big step in the transistion.
    This is being re-written to run on Linux on a headless Raspberry Pi 4.
    * Documentation for new standalone design
    * Update README.md
    * Remove obsolete config fields
    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
    [MonitorEnclosure.FCStd, MonitorPlugPlate.FCStd, MonitorTopPlate.FCStd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]
2026-02-25 Update README.md
    Documentation updates (#3)
    * More Standalone Updates
    * Update aquamon.py
    * Remove obsolute config fields
    * Add 3D print files for enclosure
    * Move email recipients back to config file
    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
    [LedCap.FCStd]
2026-02-25 LED for active alarm conditions
    When and alarm condition is active, activate an LED remotely located on the aquarium stand so that it is obvious that there is an alert. This is in addition to the email. The led will remain on as lo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
    [config.txt]
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2026-03-10 fix reset maintenance led
    Fix the maintenance led reset and also change the cloud update to once every two minutes instead of every minute.
    [config.txt]
2026-03-13 Bump sample queue for PH
    Bump up the size of the sample buffer for PH readings since it appears some spurious noise is causing an alert when there should not be one indicated. This change will then take samples over 32 seconds and through out the highest and lowest 4 readings before applying ema smoothing.
    [config.txt]
2026-03-14 Require maint mode for PH calibrate
    Only allow the PH_LOW and PH_HIGH buttons to function when the monitor is switched into maintenance mode. Also reset any partial calibration progress when maintenance mode is turned off. Also some minor restructuring/cleanup.
    [aquamon.py]
2026-03-15 Update an incorrect comment
    Fix the comment regarding the test for file exists. When running rclone lsjson, the returned list is NOT empty if the file does not exist. If the file does not exist, its name will not appear in the returned list.
    [aquamon.py]
2026-03-15 Cleanup white spaces
    Add .editorconfig file and use the EditorConfig macro in editor to cleanup white spaces and a final newline when saving files. Modify two files needing whitespace cleanup.
    [config.txt]
2026-03-15 Fix spurious PH alerts
    Getting unexpected PH alerts. Not many, one every other day, however the hourly log shows values are fine. PH probe is very high impedance and susceptible to interference. Also top-off water entering the sump at 7.0 PH may be causing a temp drop. Increase sample buffer size, remove EMA, trim 25% of the high and low values in sample buffer before averaging (was 12.5%). Also sample every 2 seconds instead of every second. Now we cross our fingers.
    [config.txt]
2026-03-15 Do no PH min/max calc in maint mode
    Do not do a mix/max value calculation when in maintenance mode since we may be calibrating the PH with calibration fluid. Also fix the day stamping for daily min/max to use local timezone. First period with start with UTC since we have not read the timezone value from the config file when the PH object is contructed.
    [aquamon.py]
2026-03-16 Fix local time reporting of min/max PH
    When the PH object is initialized, we have not read the global config values so we do not know the timezone so the reporting of the first day after the monitor is started would show UTC values for PH min/max times. This fix gets around that problem by forcing a re-initialization of the min/max the first time the PH sensor is read and then the usual re-initialization after each day ends in local time.
    [aquamon.py]
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2026-03-17 Fix comment in shutdown_button.py
    [shutdown_button.py]
2026-03-19 Added new sensor for Filter Roller
    A new sensor was added for the filter roller. When the roll is close to being empty, the new alarm will be signaled. The 3D FreeCad source files will be include for the parts involved.
    [config.txt]
2026-03-19 FreeCad files for filter roller sensor
    These are the parts to construct the sensor for the filter roller. It detects when the roll is running low.
    [FilterSensorP1.FCStd, FilterSensorP2.FCStd, FilterSensorP3.FCStd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]
2026-03-22 Add email notification for extended maint mode
    If the maintenance mode switch was active for an extended period of time, it may have been accidentally left on after maintenance activities completed. Send an email alert to warn of this possible problem since wihen maintenance mode is active, all email alerts are disabled.
    [config.txt]
2026-03-22 Fix call to set maintenance mode.
    [aquamon.py]
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2026-04-06 Move call to restore_logs
    Moving the call to restore logs until after all the checking and potential exiting is completed in the controller constructor. We don't want the previous ph log to be lost if we sys.exit from the controller's constructor due to a problem in the config.txt file. Beyond this point, exits will go through the cleanup function and the current ph log data will be saved for later restore.
    [aquamon.py]
2026-04-07 Update documentation
    Add missing capacitors to the schematic. Update the bash scripts and service files in the readme.
2026-04-14 Add feed mode
    The switch for maintenance mode was originally being used for both maintenance activities and during feeding. However, this mode is controlled completely by the position of the switch. During feeding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
    [config.txt]
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2026-04-20 Update config.txt
    Adjust main light config setting. The ambient light in the morning was causing a false alert. Increase the off-to-on transition timespan that we ignore.
    [config.txt]
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2026-04-30 Update config.txt
    preparing for the ph-ezo changes. Free up port 1 for use by the BNC socket. Removed the ambient room temp sensor and moved the water temp sensor to port 2.
    [config.txt]
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2026-05-10 Fix feed mode entry
    With the recent addition of the polling thread for the PH EZO, a timing problem was introduced such that if entering feed mode and prior to a normal sensor wakeup the PH EZO thread requests an update to the OLED, there was a small window of time when the field representing the time remaining in feed mode was not yet set, causing a divide operation failing with a numerator of None, resulting in an unhandled exception and the monitor exiting. This commit fixes problem. Also there was an error in the config file that was fixed.
    [config.txt]
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2026-05-11 Update aquamon.py
    I don't think this is solving an observed problem, however setting up the fields required for feed_mode before setting feed_mode = True is better practice. In this case, set self.feed_seconds before setting feed_mode = True since other code would normally expect feed_seconds to be set if ever it sees feed_mode=True. For example update_display assumes this.
    [aquamon.py]
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2026-05-12 PH polling frequency
    Change the polling frequency for PH reading to 30 seconds during normal operation. If maintenance mode is active, which means calibration is likely, increase to 2 seconds. Also allow the polling freq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
    [config.txt]
2026-05-12 Use event wait for ph ezo thread
    Replace time.sleep with event.wait to allow for a faster shutdown. No longer need to wait for the sleep to timeout. Also some documentation changes related to removing the PH 4502 support.
    [aquamon.py]
2026-05-15 Make cloud_file_exists generic
    The cloud_file_exists() function was being used exclusively for the override.txt file, and it was testing for that specific file name. The change makes the function usable for testing any cloud file.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
    [config.txt]
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2026-06-11 Move Top sensor to analog class
    Change the topoff sensor to analog to support three levels so we have an earlier indication when the top-off reservoir is running low. Also reduce the nag interval once an alert was resent after the 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
    [config.txt]
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2026-06-12 Cleanup setting email for alerts
    Cleanup the setting of the email address used for alerts when preparing the config.txt file for distribution
    [config.txt]
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2026-06-25 Adjust main light condition
    The ambient light was over 500 so I did not get a warning when the main light was not working. Expect a higher light level for the time the light is on.
    [config.txt]
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2026-06-29 Update config.txt
    Change calibration fluid values to match the new Milwaukee calibration solutions. Also fix some text typos
    [config.txt]
2026-06-30 Reduce writes to SSD
    The log file was being saved from tmp storage to ssd every time the monitor process was terminated. It only needs to be saved when the OS is being shutdown or rebooted. This change will stop the writing of the log file every time the monitor process is terminated.
    [aquamon.py]
2026-08-17 Fix email construction for Outlook
    When viewing the alert email in gmail, the formatting looked fine, but when viewing with outlook, the mail displayed two attached file boxes that needed to be opened up to see the contents of the email. The construction of the email was changed to build the entire contents of the email in a string and then only attach the one string. instead of multiple attaches.
    [aquamon.py]
2026-08-27 Light shade print for Maxspect LED light
    Light shade for the Maxspect LED light. The offset one is for the inner-most two shades. The clips are not centered with the square opening. The offset version can successfully be used for all the sh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
    [LightShade-Body.3mf, LightShade.FCStd, LightShadeOffset-Body.3mf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]
2026-09-04 aquamon file cleanup
    No logic changes were made. Explicit UTC time zone specified where the default of UTC was being assumed. The long code lines created by this change were shortened using temporary local variables; some fields were renamed to be more understandable, variables in the initialization of the controller object were logically grouped together.
    [aquamon.py]
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2026-09-09 Fix list comprehension handling
    Found a bug where we were iterating over the sensors and at each sensor, doing a list comprehension over all of the sensors and setting a list over and over as each sensor is processed. The resulting list is correct but wasteful cycles.
    [aquamon.py]
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2026-10-30 Maint mode status LED fix
    There was a small timing window. If Maintenance mode was selected when a alert was active, the status LED on the cabinet would get turned off instead of displaying the Maintenance mode flavor of status (LED constantly on without blinking). This is because the code thought it was resetting the active alert LED but it was actually resetting the maintenance mode LED that got turned on asynchronously when the Maintenance mode switch was activated during an active alert. The same could have occurred during Feed Mode activation as well. Both paths were fixed.
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
